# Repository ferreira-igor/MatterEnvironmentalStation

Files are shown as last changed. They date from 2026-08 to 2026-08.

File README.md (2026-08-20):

# MatterEnvironmentalStation






This project transforms an ESP32-based board into a Matter-compatible environmental monitoring station with a 20x4 LCD display. It provides seamless integration with smart home ecosystems like Alexa, Google Home, and Apple Home through the Matter protocol, while offering real-time environmental data visualization.

Designed for smart home enthusiasts and developers, this device automatically detects and commissions itself into your Matter network, providing temperature, humidity, pressure, VOC (Volatile Organic Compounds), and motion detection without complex configuration.

The system features automatic commissioning method selection (BLE or WiFi), persistent Matter configuration, robust error recovery with automatic reboot, LED status indication for easy setup, and a 20x4 LCD display for local data visualization.

## Features

- **Matter Protocol Support**: Compatible with Matter-certified smart home hubs (Alexa, Google Home, Apple Home)
- **Multi-Sensor Environmental Monitoring**:
  - **Temperature** (BME280) - ±1°C accuracy, -40°C to +85°C range
  - **Humidity** (BME280) - ±3% accuracy, 0-100% range
  - **Pressure** (BME280) - ±1 hPa accuracy, 300-1100 hPa range
  - **VOC Index** (SGP40) - Relative air quality measurement (0-500 scale)
  - **Motion Detection** (HW-MS03 PIR) - 7m range, 120° detection angle
- **20x4 LCD Display**: Shows sensor readings and system status with custom icons
- **Automatic Commissioning**: Smart method selection based on hardware capabilities
  - **BLE Commissioning** (ESP32-C3): Standard Matter commissioning via BLE - WiFi credentials provided by the commissioner app
  - **WiFi Commissioning** (Fallback): Captive portal for manual WiFi configuration when BLE is unavailable
- **Smart Reporting**: Configurable thresholds (1.0°C temperature, 3.0% humidity, 1.0 hPa pressure) to minimize network traffic
- **Automatic Recovery**: Detects and handles Matter disconnections, reboots after 60 seconds of lost connectivity
- **LED Status Indication**: Clear visual feedback - LED ON means ready for commissioning, LED OFF means commissioned
- **Real-Time Display**: LCD shows current readings, motion status, and air quality classification
- **Automatic Reconnection**: WiFi watchdog for reliable connectivity
- **Error Handling**: Graceful failure recovery with automatic restarts

## Hardware

### Required Components

- ESP32 Development Board (Tested on WeAct Studio ESP32C3, compatible with most ESP32 boards)
- BME280 Temperature, Humidity and Pressure Sensor (I2C address 0x76)
- SGP40 VOC Index Sensor (I2C address 0x59)
- HW-MS03 PIR Motion Sensor (Digital output, 3.3V compatible)
- 20x4 LCD Display (HD44780-compatible, parallel interface)
- USB Cable for programming and power
- Connecting wires

### Supported Boards

The code is tested on the WeAct Studio ESP32C3 but should work on any ESP32-based board with the following:
- Built-in LED (configurable via LED_BUILTIN)
- I2C pins (configurable via pin_i2c_scl and pin_i2c_sda)
- Parallel GPIO pins for LCD (configurable)
- BLE support (for automatic commissioning) or fallback to WiFi commissioning

### Sensor Compatibility

The BME280 and SGP40 sensors are recommended and tested. Other sensors may work with minor code modifications:
- **BME280**: Recommended (temperature, humidity, pressure)
- **BME680**: Alternative (temperature, humidity, pressure, gas resistance)
- **SGP30**: Alternative VOC sensor (would require code changes)
- **AHT10/AHT20**: Alternative humidity/temperature sensor (would require code changes)
- **HC-SR501**: Compatible PIR motion sensor (5V logic level - requires level shifting)

## Wiring

The project requires multiple connections for sensors and display:

### I2C Sensors (BME280 and SGP40)

| Component | ESP32 Pin | Description |
|---|---|---|
| BME280 VCC | 3.3V | Power supply |
| BME280 GND | GND | Ground |
| BME280 SCL | GPIO 0 | I2C Clock (WeAct Studio ESP32C3) |
| BME280 SDA | GPIO 1 | I2C Data (WeAct Studio ESP32C3) |
| SGP40 VCC | 3.3V | Power supply |
| SGP40 GND | GND | Ground |
| SGP40 SCL | GPIO 0 | I2C Clock (shared with BME280) |
| SGP40 SDA | GPIO 1 | I2C Data (shared with BME280) |

### LCD Display (Parallel 4-bit Mode)

| LCD Pin | ESP32 Pin | Description |
|---|---|---|
| VSS | GND | Ground |
| VDD | 5V or 3.3V | Power supply (check LCD specs) |
| V0 | Potentiometer | Contrast adjustment (10kΩ) |
| RS | GPIO 7 | Register Select |
| RW | GND | Read/Write (tied to GND for write-only) |
| EN | GPIO 6 | Enable |
| D4 | GPIO 5 | Data line 4 |
| D5 | GPIO 4 | Data line 5 |
| D6 | GPIO 3 | Data line 6 |
| D7 | GPIO 2 | Data line 7 |
| BLA | 5V or 3.3V | Backlight power |
| BLK | GND | Backlight ground |

### HW-MS03 PIR Motion Sensor

| Component | ESP32 Pin | Description |
|---|---|---|
| HW-MS03 VCC | 5.0V | Power supply |
| HW-MS03 GND | GND | Ground |
| HW-MS03 OUT | GPIO 10 | Digital output (HIGH = motion) |

### Built-in LED

| Component | ESP32 Pin | Description |
|---|---|---|
| Built-in LED | LED_BUILTIN | Status indicator (active LOW) |

**Note**: For other ESP32 boards, adjust the pins in the code:
- I2C pins: Change `pin_i2c_scl` and `pin_i2c_sda` (default: 0, 1)
- LCD pins: Change `pin_lcd_rs`, `pin_lcd_en`, `pin_lcd_d4`-`pin_lcd_d7` (default: 7, 6, 5, 4, 3, 2)
- Motion sensor: Change `pin_motion` (default: 10)

## Flashing

### Method 1: Pre-compiled Binary

1. Download the latest binary from the Releases page

2. Install esptool:
   ```bash
   pipx install esptool
   ```

3. Using esptool:
   ```bash
   esptool --port /dev/ttyUSB0 erase-flash
   esptool --port /dev/ttyUSB0 write-flash 0x0 MatterEnvironmentalStation.ino.merged.bin
   ```

   Replace /dev/ttyUSB0 with your actual serial port.

### Method 2: Using Arduino IDE

1. **Install ESP32 Core**:
   - Open Arduino IDE
   - Go to File > Preferences
   - Add https://raw.githubusercontent.com/espressif/arduino-esp32/gh-pages/package_esp32_index.json to Additional Boards Manager URLs
   - Go to Tools > Board > Boards Manager
   - Search for ESP32 and install esp32 by Espressif Systems (v3.3.11 or later)

2. **Install Required Libraries**:
   - Open Sketch > Include Library > Manage Libraries
   - Install the following libraries:
     - Adafruit BME280 Library by Adafruit (v2.3.0)
     - Adafruit SGP40 by Adafruit (v1.1.4)
     - LiquidCrystal by Arduino (v1.0.7) - built-in
     - Matter by Arduino (v1.2.5 or later)
     - WiFiManager by tzapu (v2.0.17) - only required when BLE commissioning is disabled

3. **Configure and Upload**:
   - Open MatterEnvironmentalStation.ino in Arduino IDE
   - Select your ESP32 board: Tools > Board > ESP32 Arduino > [Your Board Model]
   - Select the correct port: Tools > Port > [Your USB Port]
   - Select "Erase All Flash Before Sketch Upload: Enabled"
   - Select "Partition Scheme: Huge APP (3MB No OTA/1MB SPIFFS)"
   - Click Upload (arrow icon) to compile and flash

4. **Monitor Serial Output**:
   - Open Tools > Serial Monitor
   - Set baud rate to 115200
   - Observe startup logs and sensor readings

## Startup

### First Boot and Commissioning

The commissioning method depends on your ESP32 board and the CONFIG_ENABLE_CHIPOBLE flag:

#### Method 1: BLE Commissioning (Recommended - ESP32-C3)

1. **Power the Device**: Connect the ESP32 via USB or power supply
2. **LED Behavior**:
   - LED ON (LOW): Device is NOT commissioned - ready for setup
   - LED OFF (HIGH): Device IS commissioned - operating normally
3. **LCD Display**: Shows commissioning status and pairing code
4. **Commission via Smart Home App**:
   - Open your Matter-compatible app (Alexa, Google Home, Apple Home)
   - Add a new device and scan the QR code displayed in the serial monitor
   - Or enter the manual pairing code shown on the LCD and serial output
   - The app will provide WiFi credentials via BLE
   - Wait for commissioning to complete
   - The LED will turn OFF (HIGH) once commissioned
   - LCD will change to "Room Stats" display mode

#### Method 2: WiFi Commissioning (Fallback - no BLE)

1. **Power the Device**: Connect the ESP32 via USB or power supply
2. **Connect to Captive Portal**:
   - The device creates a WiFi access point (usually named MatterEnvironmental or similar)
   - Connect your phone or computer to this network
3. **Configure WiFi**:
   - Open a web browser and navigate to the captive portal (usually 192.168.4.1)
   - Enter your WiFi credentials
   - Device will connect to your WiFi network
4. **Commission via Matter**:
   - Use your Matter-compatible app to add the device
   - Scan the QR code or enter the manual pairing code shown on the LCD and serial monitor
   - The device will be commissioned to your Matter hub

### LCD Display Information

After startup and commissioning, the 20x4 LCD display shows:

**Row 0 (Status Line)**:
- Left icon: Commissioned (✔️) or Decommissioned (❌) status
- Center text: "Pin: XXXXXXXX" (pairing code) when uncommissioned, or "Room Stats" when commissioned
- Right icon: Connected (✔️) or Disconnected (❌) status

**Row 1 (Motion Status)**:
- Displays "Motion Detected!" when HW-MS03 PIR sensor triggers
- Displays "====================" when no motion detected

**Row 2 (Sensor Readings)**:
- Temperature (🌡️) with custom icon
- Humidity (💧) with custom icon  
- Pressure (↕️) with custom icon

**Row 3 (Air Quality)**:
- Based on VOC index from SGP40:
  - **Excellent** (≤ 100): "Air is Excellent"
  - **Good** (101-150): "Air is Good"
  - **Moderate** (151-250): "Air is Moderate"
  - **Poor** (251-400): "Air is Poor"
  - **Unhealthy** (> 400): "Air is Unhealthy"

### Commissioning Information

After startup, the serial monitor will display:
- Manual pairing code (numeric code for manual entry)
- QR code URL (for scanning with smart home apps)

The LCD also displays the pairing code on the top line when uncommissioned.

### LED Status Indicator

| LED State | Pin State | Meaning |
|---|---|---|
| ON (LOW) | 0 | Device NOT commissioned - ready for setup |
| OFF (HIGH) | 1 | Device IS commissioned - operating normally |

## Configuration

### Sensor Reporting Thresholds

The device uses smart reporting to minimize network traffic:

- **Temperature**: Reports when changes exceed 1.0°C (BME280 accuracy)
- **Humidity**: Reports when changes exceed 3.0% (BME280 accuracy)
- **Pressure**: Reports when changes exceed 1.0 hPa (BME280 accuracy)
- **Motion**: Reports immediately on any state change

These thresholds can be adjusted in the code:
- `temperature_diff`: Adjust as needed (default: 1.0f)
- `humidity_diff`: Adjust as needed (default: 3.0f)
- `pressure_diff`: Adjust as needed (default: 1.0f)

### Timing Parameters

| Parameter | Default | Description |
|---|---|---|
| Sensors Read Interval | 1 second | How often sensor is read |
| Display Update Interval | 5 seconds | How often LCD is updated |
| Matter Check Interval | 15 seconds | How often connection is verified |
| Matter Timeout | 3 minutes | Max disconnection time before reboot |
| WiFi Manager Timeout | 3 minutes | Captive portal timeout (WiFi method) |

### LCD Custom Icons

The firmware creates custom LCD icons for a more intuitive display:

| Icon | Description | CGRAM Index |
|---|---|---|
| 🌡️ | Temperature symbol | 0 |
| 💧 | Humidity symbol | 1 |
| ↕️ | Pressure symbol | 2 |
| ❌ | Decommissioned status | 3 |
| ✔️ | Commissioned status | 4 |
| ❌ | Disconnected status | 5 |
| ✔️ | Connected status | 6 |

## Notes

### Important Considerations

- **Matter Compatibility**: Ensure your smart home hub supports Matter (most modern hubs do)
- **Network Requirements**: Device must be on the same network as your Matter hub
- **BLE Commissioning**: Requires BLE support on the ESP32 (ESP32-C3 has built-in BLE)
- **Power Requirements**: ESP32 boards typically require 5V via USB or 3.3V from a regulated power supply
- **Sensor Placement**: For accurate readings, place the sensors away from heat sources and in open air
- **LCD Contrast**: May need adjustment via potentiometer for optimal readability
- **SGP40 Warm-Up**: VOC sensor requires stabilization time after power-on

### Performance and Limitations

- **Reading Frequency**: Sensors are read every 1 second - sufficient for environmental monitoring
- **Reporting Frequency**: Reports are sent only when thresholds are exceeded, reducing network traffic
- **Connection Recovery**: Automatic reboot after 60 seconds of disconnection ensures reliability
- **Memory Usage**: Matter library requires significant flash - use appropriate partition scheme
- **LCD Update Rate**: 5-second interval reduces display flicker and microcontroller load

### Security Considerations

- **Matter Security**: Uses Matter's built-in security and encryption
- **WiFi Credentials**: Stored in ESP32's non-volatile storage
- **BLE Commissioning**: Secure pairing using Matter's standard commissioning process
- **WiFi Manager**: Only active during setup, not during normal operation

### Troubleshooting

| Issue | Solution |
|---|---|
| BME280 not initializing | Check I2C wiring; verify address (0x76); ensure 3.3V power |
| SGP40 not initializing | Check I2C wiring; verify address (0x59); allow warm-up time |
| LCD not displaying | Check contrast potentiometer; verify wiring; check power supply |
| LCD shows garbled characters | Check LCD data pins (D4-D7); verify Enable and Register Select pins |
| LED stays ON continuously | Device is not commissioned - complete commissioning process |
| Commissioning fails | Verify Matter hub supports the device; check network connectivity |
| No sensor readings | Check I2C wiring; verify I2C addresses; check library versions |
| Device doesn't appear in Matter app | Ensure device is on the same network; reboot device and try again |
| Frequent disconnections | Check WiFi signal strength; adjust device placement |
| Motion sensor not detecting | Check wiring; verify pin 10; adjust sensitivity potentiometer |
| Serial output shows no QR code | Ensure partition scheme has enough space for Matter library |
| LCD backlight not working | Check BLA/BLK connections; verify power supply |

### VOC Index Guide

The SGP40 VOC index provides relative air quality information:

| VOC Index | Air Quality | Description |
|---|---|---|
| 0-100 | Excellent | Very low volatile organic compounds |
| 101-150 | Good | Acceptable air quality |
| 151-250 | Moderate | Some VOCs present |
| 251-400 | Poor | Elevated VOCs - consider ventilation |
| > 400 | Unhealthy | High VOCs - ventilate immediately |

Note that VOC index is relative and requires baseline calibration for absolute measurements.

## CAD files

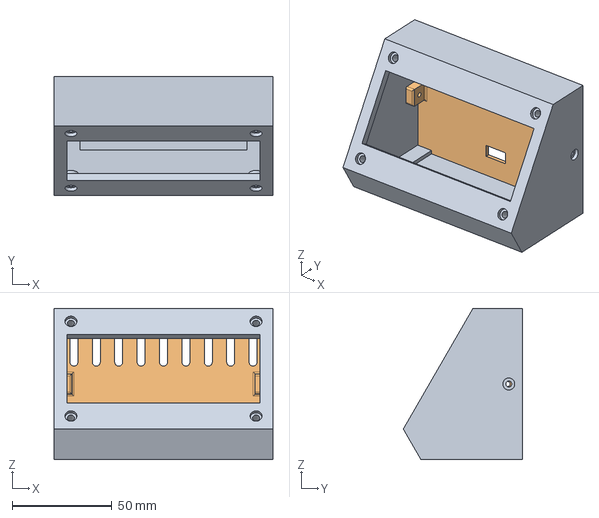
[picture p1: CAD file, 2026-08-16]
MatterEnvironmentalStation.FCStd
110.0 x 60.0 x 76.0 mm
Case
Lid

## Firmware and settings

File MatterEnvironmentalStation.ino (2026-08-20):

/**
 * @file MatterEnvironmentalStation.ino
 * @brief Matter-compatible Environmental Station with LCD Display
 * 
 * This firmware implements a Matter-compatible environmental monitoring station
 * using an ESP32C3 with multiple sensors and a 20x4 LCD display. It provides:
 * - Matter protocol support for smart home integration
 * - Temperature, humidity, pressure, and VOC sensing
 * - Motion detection (HW-MS03 PIR sensor)
 * - 20x4 LCD display with custom icons (parallel interface)
 * - Visual status indicators for Matter commissioning
 * - Automatic commissioning method selection (BLE or WiFi)
 * - Automatic reconnection and error recovery
 * 
 * @author Igor Ferreira
 * @version 1.0
 * @date 2026
 * 
 * @hardware WeAct Studio ESP32C3 (tested)
 * @sensors:
 *   - BME280: Temperature, Humidity, Pressure (I2C address 0x76)
 *   - SGP40: VOC Index (I2C address 0x59)
 *   - HW-MS03: PIR Motion Sensor (Digital pin 10, 3.3V compatible)
 * @display: 20x4 LCD with parallel interface (HD44780 compatible)
 * @toolchain Arduino IDE 2.3.10
 * @core ESP32 Arduino Core 3.3.11
 * 
 * @note Commissioning Method Selection:
 *       - ESP32-C3: Uses BLE commissioning (CONFIG_ENABLE_CHIPOBLE enabled)
 *         WiFi credentials are provided by the Matter commissioner (Alexa,
 *         Google Home, Apple Home) during commissioning via BLE
 * 
 *       - ESP32 (without BLE) or when CONFIG_ENABLE_CHIPOBLE is disabled:
 *         Uses WiFi commissioning via WiFiManager captive portal
 *         User manually configures WiFi credentials through a web interface
 * 
 *       The code automatically adapts to the available commissioning method
 *       based on the CONFIG_ENABLE_CHIPOBLE compilation flag.
 * 
 * @note LED Behavior (Active LOW - typical for ESP32 boards):
 *       - LED ON (LOW): Device is NOT commissioned - ready for setup
 *       - LED OFF (HIGH): Device IS commissioned - operating normally
 * 
 * @note LCD Interface: Parallel 4-bit mode
 *       - RS (Register Select): pin 7
 *       - EN (Enable): pin 6
 *       - D4-D7 (Data lines): pins 5, 4, 3, 2
 *       - Uses LiquidCrystal library for HD44780-compatible displays
 * 
 * @note LCD Icons (custom characters stored in CGRAM):
 *       - Temperature (℃) - Index 0
 *       - Humidity (%) - Index 1
 *       - Pressure (hPa) - Index 2
 *       - Commissioned icon - Index 5
 *       - Decommissioned icon - Index 4
 *       - Connected icon - Index 7
 *       - Disconnected icon - Index 6
 * 
 * @note I2C pins: SCL=0, SDA=1 (WeAct Studio ESP32C3)
 *       LCD pins: RS=7, EN=6, D4=5, D5=4, D6=3, D7=2
 *       Motion sensor: HW-MS03 on pin 10 (3.3V logic level)
 */

#include <Arduino.h>

#include <Wire.h>
#include <Adafruit_BME280.h>  // https://github.com/adafruit/Adafruit_BME280_Library/releases/tag/2.3.0
#include <Adafruit_SGP40.h>   // https://github.com/adafruit/Adafruit_SGP40/releases/tag/1.1.4
#include <LiquidCrystal.h>

#include <Matter.h>

//=============================================================================
// Conditional WiFi Configuration
//=============================================================================

/**
 * @brief WiFiManager is included only when BLE commissioning is disabled
 * 
 * The commissioning method is determined at compile time:
 * 
 * 1. BLE Commissioning (CONFIG_ENABLE_CHIPOBLE = 1):
 *    - Used by ESP32-C3 and other boards with BLE support
 *    - WiFi credentials are provided by the Matter commissioner app
 *      (Alexa, Google Home, Apple Home) via BLE
 *    - WiFiManager is NOT used
 *    - This is the recommended method for most ESP32 boards
 * 
 * 2. WiFi Commissioning (CONFIG_ENABLE_CHIPOBLE = 0):
 *    - Used as fallback for boards without BLE or for debugging
 *    - ESP32 creates a captive portal WiFi network
 *    - User connects and configures WiFi via web interface
 *    - WiFiManager handles the configuration process
 * 
 * The conditional compilation ensures the code works on both BLE-capable
 * and non-BLE boards without modification.
 */
#if !CONFIG_ENABLE_CHIPOBLE
#include <WiFi.h>
#include <WiFiManager.h>  // https://github.com/tzapu/WiFiManager/releases/tag/v2.0.17

/** @brief WiFiManager instance for captive portal (BLE commissioning disabled) */
WiFiManager wm;
#endif

//=============================================================================
// Hardware Configuration Constants
//=============================================================================

//---------------------------------------------------------------------------
// I2C Pins (for BME280 and SGP40 sensors)
//---------------------------------------------------------------------------

/** @brief I2C SCL pin (GPIO 0 - WeAct Studio ESP32C3) */
constexpr uint8_t pin_i2c_scl = 0;

/** @brief I2C SDA pin (GPIO 1 - WeAct Studio ESP32C3) */
constexpr uint8_t pin_i2c_sda = 1;

//---------------------------------------------------------------------------
// LCD Parallel Interface Pins (4-bit mode)
//---------------------------------------------------------------------------

/**
 * @brief LCD D7 pin (GPIO 2) - Most significant data bit
 * 
 * In 4-bit mode, D7 is the highest-order data bit.
 * Data is sent in two 4-bit nibbles: high nibble (D4-D7) first,
 * followed by low nibble (D0-D3).
 */
constexpr uint8_t pin_lcd_d7 = 2;

/**
 * @brief LCD D6 pin (GPIO 3) - Data bit 6
 */
constexpr uint8_t pin_lcd_d6 = 3;

/**
 * @brief LCD D5 pin (GPIO 4) - Data bit 5
 */
constexpr uint8_t pin_lcd_d5 = 4;

/**
 * @brief LCD D4 pin (GPIO 5) - Data bit 4 (least significant in 4-bit mode)
 */
constexpr uint8_t pin_lcd_d4 = 5;

/**
 * @brief LCD Enable pin (GPIO 6)
 * 
 * A high-to-low pulse on this pin latches data from the data lines
 * into the LCD controller.
 */
constexpr uint8_t pin_lcd_en = 6;

/**
 * @brief LCD Register Select pin (GPIO 7)
 * 
 * Determines if data is interpreted as:
 * - LOW (0): Command/instruction
 * - HIGH (1): Character data to display
 */
constexpr uint8_t pin_lcd_rs = 7;

//---------------------------------------------------------------------------
// HW-MS03 PIR Motion Sensor
//---------------------------------------------------------------------------

/**
 * @brief HW-MS03 PIR Motion Sensor pin (GPIO 10)
 * 
 * HW-MS03 specifications:
 * - Operating Voltage: 3.3V to 5V DC (3.3V compatible)
 * - Output: Digital signal (3.3V logic level)
 * - Detection Range: Up to 7 meters (adjustable)
 * - Detection Angle: 120 degrees
 * - Output HIGH: Motion detected
 * - Output LOW: No motion detected
 * - Warm-up time: ~2 seconds after power-on
 * 
 * Connection:
 * - VCC: 3.3V
 * - GND: GND
 * - OUT: GPIO 10
 * 
 * Internal pulldown resistor ensures stable LOW when no motion.
 * 
 * @note HW-MS03 is a generic HC-SR501 variant with 3.3V compatibility
 * @note The sensor has adjustable sensitivity and time delay potentiometers
 */
constexpr uint8_t pin_motion = 10;

//---------------------------------------------------------------------------
// Built-in LED
//---------------------------------------------------------------------------

/**
 * @brief Built-in LED pin for status indication (Active LOW)
 * 
 * The LED is connected between VCC and the GPIO pin (common on ESP32 boards).
 * - LOW = LED ON (not commissioned - ready for setup)
 * - HIGH = LED OFF (commissioned - operating normally)
 * 
 * @note Active LOW is typical for ESP32 boards where the LED is connected
 *       to VCC through a current-limiting resistor
 */
constexpr uint8_t pin_led = LED_BUILTIN;

//=============================================================================
// Sensor Data Variables
//=============================================================================

/** @brief Current temperature reading in Celsius */
float current_temperature = 0.0f;

/** @brief Last temperature value reported to Matter */
float reported_temperature = 0.0f;

/**
 * @brief Temperature change threshold for reporting
 * 
 * Only report temperature changes greater than this value (1.0°C)
 * to avoid excessive Matter updates.
 * 
 * @note BME280 temperature accuracy is approximately ±1°C
 */
const float temperature_diff = 1.0f;

/** @brief Current humidity reading in percentage */
float current_humidity = 0.0f;

/** @brief Last humidity value reported to Matter */
float reported_humidity = 0.0f;

/**
 * @brief Humidity change threshold for reporting
 * 
 * Only report humidity changes greater than this value (3.0%)
 * to avoid excessive Matter updates.
 * 
 * @note BME280 humidity accuracy is approximately ±3%
 */
const float humidity_diff = 3.0f;

/** @brief Current pressure reading in hPa (hectopascals) */
float current_pressure = 0.0f;

/** @brief Last pressure value reported to Matter */
float reported_pressure = 0.0f;

/**
 * @brief Pressure change threshold for reporting
 * 
 * Only report pressure changes greater than this value (1.0 hPa)
 * to avoid excessive Matter updates.
 * 
 * @note BME280 pressure accuracy is approximately ±1 hPa
 */
const float pressure_diff = 1.0f;

/** @brief Current VOC (Volatile Organic Compounds) index from SGP40 */
int32_t current_voc = 0;

/** @brief Last VOC value reported to Matter (not currently used) */
int32_t reported_voc = 0;

/**
 * @brief Current motion detection state from HW-MS03 sensor
 * 
 * true = motion detected (sensor output HIGH)
 * false = no motion (sensor output LOW)
 */
bool current_motion = false;

/**
 * @brief Last motion state reported to Matter
 * 
 * Used to detect changes and avoid redundant updates.
 */
bool reported_motion = false;

//=============================================================================
// Timing Constants
//=============================================================================

/** @brief Interval between sensor readings */
const uint32_t sensors_read_interval = 1000;

/** @brief Interval for LCD display updates */
const uint32_t display_update_interval = 5000;

/** @brief Interval for Matter connection checks */
const uint32_t matter_check_interval = 15000;

/** @brief Maximum time without Matter connection before reboot */
const uint32_t matter_timeout = 180000;

/**
 * @brief Counter for consecutive Matter disconnections
 * 
 * Incremented when device is commissioned but not connected.
 * Reset to 0 when connection is restored.
 */
uint8_t matter_disconnect_counter = 0;

/** @brief Timestamp of last sensor reading */
uint32_t last_sensors_read = 0;

/** @brief Timestamp of last LCD display update */
uint32_t last_display_update = 0;

/** @brief Timestamp of last Matter connection check */
uint32_t last_matter_check = 0;

//=============================================================================
// LCD Configuration and Custom Icons
//=============================================================================

/** @brief Number of LCD columns (20 characters) */
constexpr uint8_t lcd_cols = 20;

/** @brief Number of LCD rows (4 lines) */
constexpr uint8_t lcd_rows = 4;

/**
 * @brief Custom LCD icon: Temperature symbol (℃)
 * 
 * 5x8 pixel bitmap representing a thermometer with degree symbol
 * Stored in LCD CGRAM (Character Generator RAM)
 */
uint8_t lcd_icon_temperature[8] = {
  0b00100,
  0b01010,
  0b01010,
  0b01010,
  0b01110,
  0b11111,
  0b11111,
  0b01110
};

/**
 * @brief Custom LCD icon: Humidity symbol (%)
 * 
 * 5x8 pixel bitmap representing a droplet for humidity
 * Stored in LCD CGRAM (Character Generator RAM)
 */
uint8_t lcd_icon_humidity[8] = {
  0b00100,
  0b00100,
  0b01010,
  0b01010,
  0b10001,
  0b10001,
  0b10001,
  0b01110
};

/**
 * @brief Custom LCD icon: Pressure symbol (hPa)
 * 
 * 5x8 pixel bitmap representing an aneroid barometer
 * Stored in LCD CGRAM (Character Generator RAM)
 */
uint8_t lcd_icon_pressure[8] = {
  0b11111,
  0b01110,
  0b00100,
  0b00000,
  0b00000,
  0b00100,
  0b01110,
  0b11111
};

/**
 * @brief Custom LCD icon: Decommissioned state
 * 
 * 5x8 pixel bitmap showing device is not commissioned
 * (Hourglass/sand timer indicating setup needed)
 * Stored in LCD CGRAM (Character Generator RAM)
 */
uint8_t lcd_icon_decommissioned[8] = {
  0b10100,
  0b01000,
  0b10100,
  0b00000,
  0b01010,
  0b10101,
  0b10101,
  0b10101
};

/**
 * @brief Custom LCD icon: Commissioned state
 * 
 * 5x8 pixel bitmap showing device is commissioned
 * (Check mark or confirmation symbol)
 * Stored in LCD CGRAM (Character Generator RAM)
 */
uint8_t lcd_icon_commissioned[8] = {
  0b00010,
  0b10100,
  0b01000,
  0b00000,
  0b01010,
  0b10101,
  0b10101,
  0b10101
};

/**
 * @brief Custom LCD icon: Disconnected state
 * 
 * 5x8 pixel bitmap showing Matter connection lost
 * (Broken chain or disconnected symbol)
 * Stored in LCD CGRAM (Character Generator RAM)
 */
uint8_t lcd_icon_disconnected[8] = {
  0b10100,
  0b01000,
  0b10100,
  0b00001,
  0b00011,
  0b00111,
  0b01111,
  0b11111
};

/**
 * @brief Custom LCD icon: Connected state
 * 
 * 5x8 pixel bitmap showing Matter connection active
 * (Chain link or connected symbol)
 * Stored in LCD CGRAM (Character Generator RAM)
 */
uint8_t lcd_icon_connected[8] = {
  0b00010,
  0b10100,
  0b01000,
  0b00001,
  0b00011,
  0b00111,
  0b01111,
  0b11111
};

//=============================================================================
// LCD Icon Index Definitions
//=============================================================================

/** @brief Index for temperature icon in LCD CGRAM (character 0) */
constexpr uint8_t lcd_index_temperature = 0;

/** @brief Index for humidity icon in LCD CGRAM (character 1) */
constexpr uint8_t lcd_index_humidity = 1;

/** @brief Index for pressure icon in LCD CGRAM (character 2) */
constexpr uint8_t lcd_index_pressure = 2;

/** @brief Index for decommissioned icon in LCD CGRAM (character 3) */
constexpr uint8_t lcd_index_decommissioned = 3;

/** @brief Index for commissioned icon in LCD CGRAM (character 4) */
constexpr uint8_t lcd_index_commissioned = 4;

/** @brief Index for disconnected icon in LCD CGRAM (character 5) */
constexpr uint8_t lcd_index_disconnected = 5;

/** @brief Index for connected icon in LCD CGRAM (character 6) */
constexpr uint8_t lcd_index_connected = 6;

//=============================================================================
// LCD and Sensor Initialization
//=============================================================================

/**
 * @brief LCD instance with parallel 4-bit interface
 * 
 * Connections (LiquidCrystal library pins):
 * - RS (Register Select): pin_lcd_rs (GPIO 7)
 * - EN (Enable): pin_lcd_en (GPIO 6)
 * - D4 (Data 4): pin_lcd_d4 (GPIO 5)
 * - D5 (Data 5): pin_lcd_d5 (GPIO 4)
 * - D6 (Data 6): pin_lcd_d6 (GPIO 3)
 * - D7 (Data 7): pin_lcd_d7 (GPIO 2)
 * 
 * The LiquidCrystal library handles the 4-bit communication protocol
 * automatically, sending data in two 4-bit nibbles (high nibble first).
 * 
 * @note HD44780-compatible LCD controller required
 * @note 4-bit mode uses only D4-D7 pins (D0-D3 are not connected)
 */
LiquidCrystal lcd(pin_lcd_rs, pin_lcd_en, pin_lcd_d4, pin_lcd_d5, pin_lcd_d6, pin_lcd_d7);

/** @brief I2C address for BME280 sensor (0x76 - can be 0x77 depending on ADDR pin) */
constexpr uint8_t bme280_addr = 0x76;

/** @brief BME280 sensor instance (temperature, humidity, pressure) */
Adafruit_BME280 bme;

/** @brief SGP40 sensor instance (VOC index - volatile organic compounds) */
Adafruit_SGP40 sgp;

//=============================================================================
// Matter Endpoints
//=============================================================================

/**
 * @brief Matter Temperature Sensor endpoint
 * 
 * Represents the temperature sensor as a Matter device.
 * Provides standard Matter temperature measurement cluster.
 */
MatterTemperatureSensor temperatureSensor;

/**
 * @brief Matter Humidity Sensor endpoint
 * 
 * Represents the humidity sensor as a Matter device.
 * Provides standard Matter humidity measurement cluster.
 */
MatterHumiditySensor humiditySensor;

/**
 * @brief Matter Pressure Sensor endpoint
 * 
 * Represents the pressure sensor as a Matter device.
 * Provides standard Matter pressure measurement cluster.
 */
MatterPressureSensor pressureSensor;

/**
 * @brief Matter Occupancy Sensor endpoint
 * 
 * Represents the motion sensor (HW-MS03) as a Matter device.
 * Provides standard Matter occupancy measurement cluster.
 */
MatterOccupancySensor occupancySensor;

//=============================================================================
// Sensor Reading Functions
//=============================================================================

/**
 * @brief Read all sensors and update current values
 * 
 * Reads data from BME280 (temperature, humidity, pressure),
 * SGP40 (VOC index), and HW-MS03 PIR motion sensor.
 * 
 * Sensor details:
 * - BME280 (I2C address 0x76):
 *   * Temperature: ±1°C accuracy, -40°C to +85°C range
 *   * Humidity: ±3% accuracy, 0-100% range
 *   * Pressure: ±1 hPa accuracy, 300-1100 hPa range
 * 
 * - SGP40 (I2C address 0x59):
 *   * VOC Index: 0-500 scale (relative air quality)
 *   * Requires temperature and humidity for compensation
 *   * Higher values indicate more VOCs in the air
 *   * Uses MOX (metal-oxide) technology
 * 
 * - HW-MS03 (PIR Motion Sensor on pin 10):
 *   * Output HIGH (3.3V) when motion detected
 *   * Output LOW (0V) when no motion
 *   * Detection range: up to 7 meters
 *   * Detection angle: 120 degrees
 *   * Warm-up time: ~2 seconds
 * 
 * @note Called every sensors_read_interval
 * @note SGP40 reading uses current temperature and humidity for compensation
 * @note All readings are validated (checked for NaN)
 * 
 * @warning If a sensor fails, an error message is printed but reading continues
 */
void readSensors() {
  // Read temperature from BME280
  float t = bme.readTemperature();

  if (!isnan(t)) {
    current_temperature = t;
    Serial.print("Temperature: ");
    Serial.print(current_temperature);
    Serial.println("C");
  } else {
    Serial.println("Error reading temperature!");
  }

  // Read humidity from BME280
  float h = bme.readHumidity();

  if (!isnan(h)) {
    current_humidity = h;
    Serial.print("Humidity: ");
    Serial.print(current_humidity);
    Serial.println("%");
  } else {
    Serial.println("Error reading humidity!");
  }

  // Read pressure from BME280 (convert Pa to hPa)
  float p = bme.readPressure();

  if (!isnan(p)) {
    current_pressure = p / 100.0f;  // Convert Pa to hPa
    Serial.print("Pressure: ");
    Serial.print(current_pressure);
    Serial.println("hPA");
  } else {
    Serial.println("Error reading pressure!");
  }

  // Read VOC index from SGP40 (compensated with temperature and humidity)
  current_voc = sgp.measureVocIndex(current_temperature, current_humidity);
  Serial.print("VOC Index: ");
  Serial.println(current_voc);

  // Read HW-MS03 PIR motion sensor state
  // HIGH = motion detected, LOW = no motion
  current_motion = digitalRead(pin_motion);
  Serial.print("Motion: ");
  Serial.println(current_motion);
}

//=============================================================================
// LCD Display Functions
//=============================================================================
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
void loop() {
  uint32_t current_time = millis();

  // Task 1: Read sensors
  if (current_time - last_sensors_read >= sensors_read_interval) {
    last_sensors_read = current_time;
    readSensors();
    updateMatter();
  }

  // Task 2: Update LCD display
  if (current_time - last_display_update >= display_update_interval) {
    last_display_update = current_time;
    updateDisplay();
  }

  // Task 3: Check Matter connection
  if (current_time - last_matter_check >= matter_check_interval) {
    last_matter_check = current_time;
    checkMatter();
  }
}

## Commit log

2026-08-20 Refactor code structure for improved readability and maintainability
    [MatterEnvironmentalStation.FCStd]
2026-08-20 Adiciona a biblioteca LiquidCrystal ao fluxo de trabalho de compilação
2026-08-20 Atualiza ícones no display LCD para melhor visualização do status e leituras dos sensores
